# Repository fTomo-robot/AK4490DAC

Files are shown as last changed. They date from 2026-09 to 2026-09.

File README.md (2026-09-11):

# AK4490DAC

AKM(旭化成エレクトロニクス)の **AK4490**(32bit プレミアムDAC)と **AK4118**(SPDIFレシーバー)を使ったUSB DACのKiCadプロジェクト。

## 経緯

元の回路図(Eagle形式、`NEWDAC.sch`)はWindows PC上にのみ存在しており、このリポジトリ作成時点では発見できていません。
このプロジェクトは、JLCPCBに発注した際の製造データ(ガーバー・BOM・部品配置データ)から構成部品を復元し、KiCadで新規に組み直した上で、USB入力段・電源・出力段を改良したものです。

- `reference/NEWDAC_original_BOM.txt` : 元のEagle回路図から書き出された部品表(オリジナル、参考用)
- `reference/PnP_NEWDAC_*.txt` : 元の部品配置(Pick & Place)データ(参考用)

## 回路構成(改良版)

```
PC --USB--> SA9227(非同期USBオーディオ) --I2S--------------------+
                                                                  |
   (同軸/光)--SPDIF--> DA103C(絶縁トランス) --> AK4118(SPDIFレシーバ)
                                                    |  I2S        |
                                                    v              v
                                                74LS157(2:1 I2Sセレクタ)
                                                                  |
                                                                  v
                                                             AK4490(DAC)
                                                                  |  差動アナログ出力
                                                                  v
                                                    MUSES8920 x3(差動→SE変換 + LPF)
                                                                  |
                                                                  v
                                                              ライン出力
```

- **USB入力(U2 SA9227)**: Savitech製の非同期USBオーディオストリーミングコントローラ。32bit/384kHzまで対応し、旧PCM2704C(16bit/48kHz止まり)のボトルネックを解消。SPDIF送受信も内蔵
  - **要注意**: SA9227は動作に外部I2C EEPROM(`U8`, 24LC02)へのファームウェア書き込みが必須。書き込み用のファームウェアイメージは別途入手が必要
- **入力切り替え(U7, 74LS157)**: USB(SA9227のI2S出力)とSPDIF(AK4118のI2S出力)を1系統に統合してAK4490へ
- **絶縁(T1, DA103C)**: Murata製パルストランスでSPDIF入力経路をガルバニック絶縁
- **SPDIF受信(U5, AK4118)**: 同軸/光デジタル入力を受信・PLLでクロック再生成しI2Sに変換
- **D/A変換(U6, AK4490)**: 差動電流出力を生成。リファレンス電圧まわりは徹底したデカップリング
- **出力段(IC5-7, MUSES8920)**: 旧TL072から低ノイズ・低歪みのオーディオ用オペアンプに変更(ピン互換のドロップイン)
- **電源(IC1-4, ADP7142)**: 旧LM1117(ノイズ大きめの汎用LDO)から、Analog Devices製の低ノイズLDOに変更。3.3V×3・5.0V×1
- **リセット(U3/U4, TCM809)**: AK4118・AK4490それぞれのパワーオンリセットシーケンシング

## 注意事項

- `AK4118` / `AK4490` / `DA103C` / `SA9227` のシンボル・フットプリントは、旭化成系は過去の検証済みEagleライブラリから、SA9227は公式データシート(Savitech BRAVO-DSD SA9227 v1.3)のピン配置表から復元したもの
- 実際の配線(ネット接続)はまだ行っていない。KiCad上で全ICを配置しただけの状態
- SA9227のファームウェア(EEPROM書き込みイメージ)は別途入手・準備が必要
- ADP7142/MUSES8920/TCM809/BSS138/74LS157はKiCad標準ライブラリのシンボル・フットプリントをそのまま使用

## 次回作業予定(方針変更)

USB入力段について、SA9227のファームウェア/EEPROM書き込みが手間・コスト面で見合わないと判断し、**方針を変更**することにした(2026-09-12時点、回路図は未反映):

- **USB入力ICの自作(SA9227)はやめる**。市販の完成品コンバータを外付けで使う
  - 候補: Cubilux USB-C to SPDIF(TOSLINK)変換アダプタ(¥2,500前後、48kHz/24bit〜192kHz/24bit、ドライバ不要)
  - 元のBOMがUSB Type-Cコネクタ(`TYPE-C-31-M-12`)だったため、変換アダプタもそのまま挿せる
- 上記に伴い、次回は回路図から **U2(SA9227)・U8(24LC02 EEPROM)・U7(74LS157マルチプレクサ)を撤去**
- 代わりに **AK4118のSPDIF入力(RX0ピン)へTOSLINK光入力ジャックを追加**
- 検討したが採用しなかった他のUSB IC案(参考): PCM2704C(現状維持案)、TE7022L(EEPROM任意で24bit/96kHz)、CM6631A(LQFP-100・要ファーム)、CP2114(Silicon Labs製・EOL/48kHz止まりのため見送り)、Amanero Combo384モジュール(高性能だが¥15,400と割高)

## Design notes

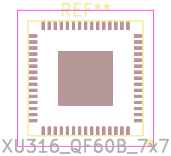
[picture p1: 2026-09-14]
.codex-work/fpcheck/XU316_QF60B_7x7.png

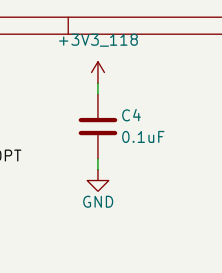
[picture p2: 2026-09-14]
.codex-work/power-layout/bypass.png

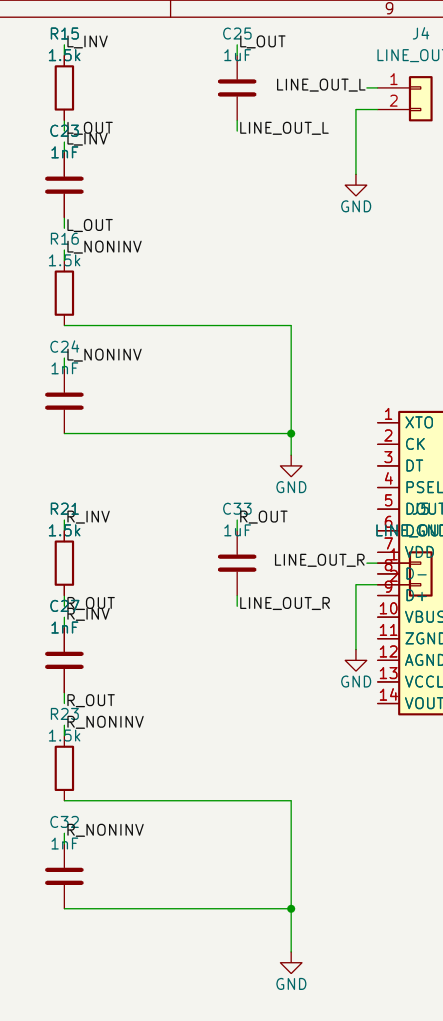
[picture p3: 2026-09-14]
.codex-work/power-layout/filters.png

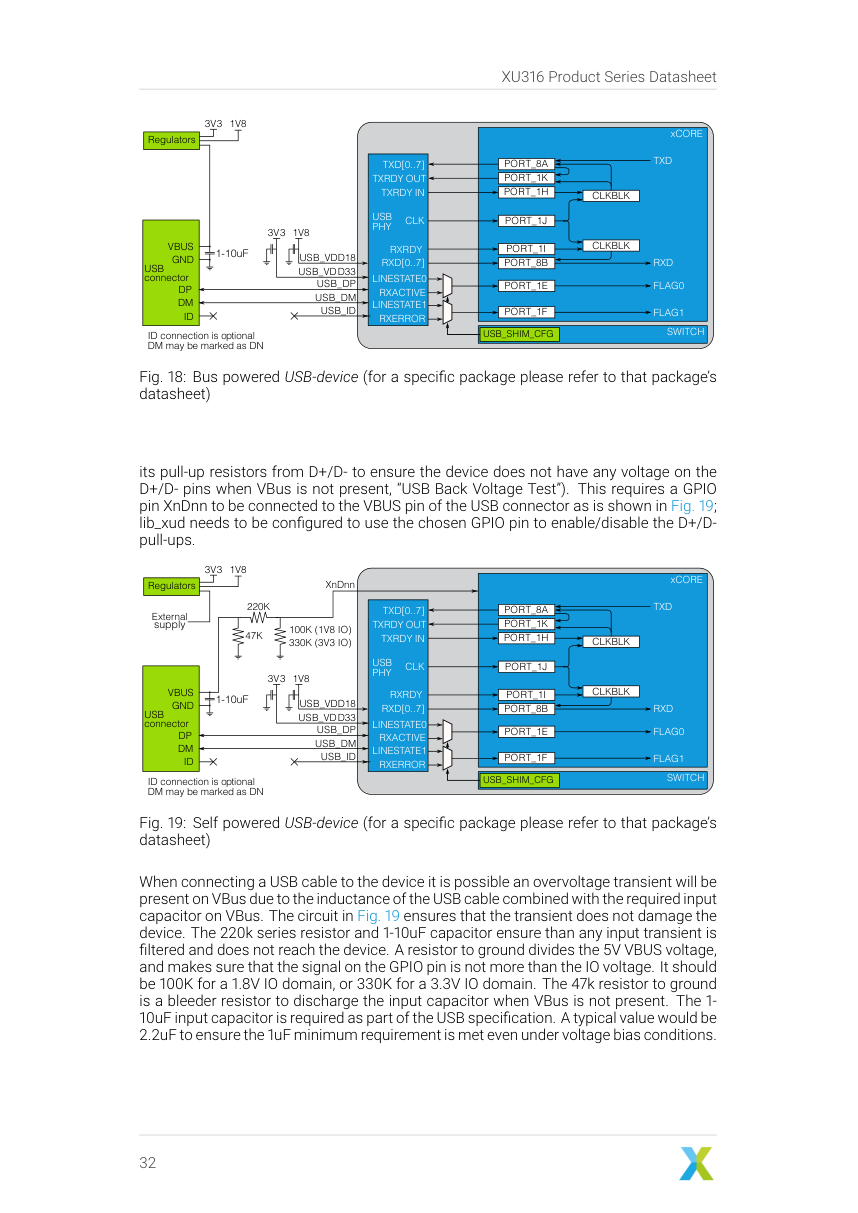
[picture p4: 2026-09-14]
.codex-work/xu316/sources/xmos-page32.png

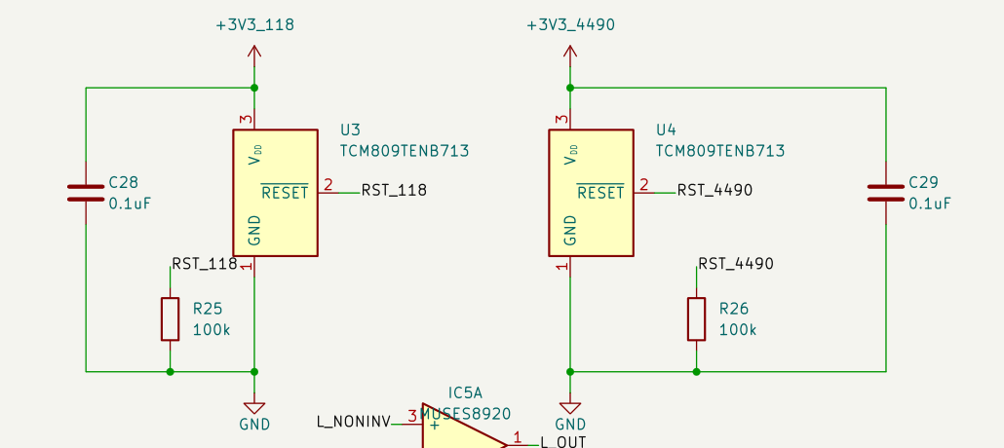
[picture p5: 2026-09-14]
.codex-work/power-layout/reset.png

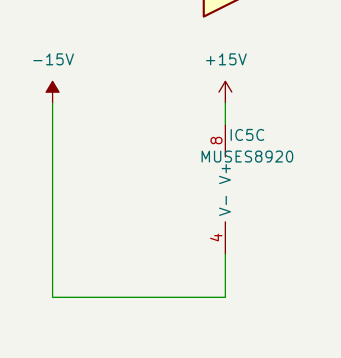
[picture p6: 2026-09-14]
.codex-work/power-layout/analog.png

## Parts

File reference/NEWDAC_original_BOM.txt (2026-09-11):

Partlist exported from C:/Users/zhigu/Desktop/NEWDAC.sch at 2023/01/06 15:23

Qty Value         Device          Package               Parts                                                                                                                                                                                                     Description                                                                                                 AVAILABILITY COPYRIGHT                                                DESCRIPTION                                                            MANUFACTURER_PART_NUMBER MF                   MFR_NAME          MP            MPN          OC_FARNELL OC_NEWARK PACKAGE                  POPULARITY PRICE PURCHASE-URL                                                   SPICEPREFIX TP_SIGNAL_NAME
21                C-EU050-024X044 C050-024X044          C2, C3, C5, C6, C7, C8, C10, C11, C13, C14, C15, C16, C17, C18, C19, C20, C21, C22, C23, C24, C25                                                                                                         CAPACITOR, European symbol                                                                                                                                                                                                                                                                                                                                                                        33                                                                              C                         
4                 CPOL-EUE5-10.5  E5-10,5               C1, C4, C9, C12                                                                                                                                                                                           POLARIZED CAPACITOR, European symbol                                                                                                                                                                                                                                                                                                                                                              23                                                                              C                         
20  1608          1608            CON                   U$7, U$17, U$18, U$21, U$22, U$23, U$24, U$25, U$26, U$28, U$29, U$36, U$37, U$43, U$44, U$45, U$46, U$51, U$61, U$62                                                                                                                                                                                                                                                                                                                                                                                                                                                                                                                                                                                                 
18  25V100        25V100          25V100                U$6, U$11, U$12, U$13, U$15, U$16, U$19, U$20, U$27, U$31, U$34, U$35, U$38, U$39, U$41, U$42, U$49, U$60                                                                                                                                                                                                                                                                                                                                                                                                                                                                                                                                                                                                             
1   946H          946H            946H                  U$8                                                                                                                                                                                                                                                                                                                                                                                                                                                                                                                                                                                                                                                                                                                   
1   AK4118        AK4118          QFP50P900X900X160-48N U$1                                                                                                                                                                                                                                                                                                                                                                                                                                                                                                                                                                                                                                                                                                                   
1   AK4490        AK4490          QFP50P900X900X160-48N U$2                                                                                                                                                                                                                                                                                                                                                                                                                                                                                                                                                                                                                                                                                                                   
2   B2B-PH-K-S    B2B-PH-K-S      B2B-PH-K-S            X2, X4                                                                                                                                                                                                    JST PH series header 2.00mm pitch disconnectable crimp style connectors, vertical (side entry type), 2 pins                                                                                                                                                                                                                                                                                                                                                                                                 
1   B3B-PH-K-S    B3B-PH-K-S      B3B-PH-K-S            X3                                                                                                                                                                                                        JST PH series header 2.00mm pitch disconnectable crimp style connectors, vertical (side entry type), 3 pins                                                                                                                                                                                                                                                                                                                                                                                                 
1   B4B-PH-K-S    B4B-PH-K-S      B4B-PH-K-S            X1                                                                                                                                                                                                        JST PH series header 2.00mm pitch disconnectable crimp style connectors, vertical (side entry type), 4 pins                                                                                                                                                                                                                                                                                                                                                                                                 
2   BNX016-01     BNX016-01       FIL_BNX016-01         FL1, FL2                                                                                                                                                                                                  Check availability                                                                                          In Stock                                                               LC EMI Filter 5th Order Low Pass 2 Channel - 15 A Block, 4 Lead                                Murata Electronics                     BNX016-01                                       Block-4 Murata                      None  https://pricing.snapeda.com/search/part/BNX016-01/?ref=eda                               
1   BSS138        BSS138          SOT23                 Q1                                                                                                                                                                                                        BSS138 N-Channel Logic Level Enhancement Mode Field Effect Transistor                                                                                                                                                                                                             Fairchild                                            BSS138       9845330    67R2009                                                                                                                                      
1   DA103C        DA103C          DA103C_MUR            T1                                                                                                                                                                                                                                                                                                                                 Copyright (C) 2022 Ultra Librarian. All rights reserved.                                                                        DA103C                                        Murata                                                                                                                                                                                               
3   FG            FG              FG                    U$33, U$40, U$47                                                                                                                                                                                                                                                                                                                                                                                                                                                                                                                                                                                                                                                                                                      
3   LM1117MP-3.3  LM1117MP-3.3    SOT223                IC3, IC5, IC6                                                                                                                                                                                             800mA Low-Dropout Linear Regulator                                                                                                                                                                                                                                                Texas Instruments                                    LM1117MP-3.3 9778195    28X3416                                                                                                                                      
1   LM1117MP-5.0  LM1117MP-5.0    SOT223                IC4                                                                                                                                                                                                       800mA Low-Dropout Linear Regulator                                                                                                                                                                                                                                                Texas Instruments                                    LM1117MP-5.0 9778209    28X3417                                                                                                                                      
1   MCWI03        MCWI03          MCWI03                U$57                                                                                                                                                                                                                                                                                                                                                                                                                                                                                                                                                                                                                                                                                                                  
1   PCM2704CDBR   PCM2704CDBR     DB28                  U1                                                                                                                                                                                                                                                                                                                                 Copyright (C) 2022 Ultra Librarian. All rights reserved.                                                                        PCM2704CDBR                                   Texas Instruments                                                                                                                                                                                    
1   Q             Q               Q                     U$3                                                                                                                                                                                                                                                                                                                                                                                                                                                                                                                                                                                                                                                                                                                   
45  R             R               1608                  1, 2, 11, 12, 13, 14, 15, 16, 17, 18, 19, 20, 21, 22, 23, 24, 25, 26, 27, 28, 29, 30, 31, 32, 33, 34, 35, 36, 37, 38, 39, 40, U$9, U$10, U$14, U$32, U$48, U$50, U$52, U$53, U$54, U$55, U$56, U$58, U$59                                                                                                                                                                                                                                                                                                                                                                                                                                                                                                             
1   SN74LS06NSR   SN74LS06NSR     SOIC127P780X200-14N   U2                                                                                                                                                                                                        HEX INVERTER BUFFERS Check availability                                                                     In Stock                                                               6-ch, 4.75-V to 5.25-V bipolar inverters with open-collector outputs                           Texas Instruments                      SN74LS06NSR                                     SOP-14 Texas Instruments            None  https://pricing.snapeda.com/search/part/SN74LS06NSR/?ref=eda                             
2   TCM809RENB713 TCM809RENB713   SOT95P237X112-3N      U$4, U$5                                                                                                                                                                                                  Check availability                                                                                          In Stock                                                               Processor Supervisor 2.63V 1 Active Low/Push-Pull 3-Pin SOT-23 T/R                             Microchip Technology                   TCM809RENB713                                   SOT-23 Microchip                    None  https://pricing.snapeda.com/search/part/TCM809RENB713/?ref=eda                           
3   TL072P        TL072P          DIL08                 IC1, IC2, IC7                                                                                                                                                                                             OP AMP                                                                                                                                                                                                                                                                                                                                                                                            13                                                                                                        
2   TPB1,27       TPB1,27         B1,27                 INT0, INT1                                                                                                                                                                                                Test pad                                                                                                                                                                                                                                                                                                                                                                                          19

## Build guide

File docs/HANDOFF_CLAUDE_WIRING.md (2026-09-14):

# Claude向け引継ぎ資料：AK4490DAC 回路図配線

作成日: 2026-09-14  
作成者: Codex

## 依頼内容

ユーザーからの依頼は「回路図で配線を進められそうな部分は進める。都度、部品位置は見やすいように変更してよい」。

不確かな仕様を推測で確定せず、公式データシートと既存の部品Descriptionから意図を判断できる部分まで配線した。

## 作業対象

現在の編集済みプロジェクト:

```text
C:\Users\ftomo\Documents\ChatGPT\AK4490DAC
```

主要ファイル:

```text
AK4490DAC.kicad_sch       編集済み回路図（作業継続対象）
AK4490DAC.kicad_sym       プロジェクト専用シンボル
AK4490DAC.kicad_pro       KiCadプロジェクト設定
AK4490DAC.kicad_pcb       基板。今回未編集
AK4490DAC_wired.pdf       編集後の確認用PDF
docs/WIRING_PROGRESS.md   今回の変更概要
```

コピー元は次の既存リポジトリ。ただし、コピー元にはユーザーまたは別セッションの未コミット変更があったため、今回の編集結果はまだ戻していない。

```text
C:\Users\ftomo\Documents\GitHub\AK4490DAC
```

コピー元の確認時点の状態:

```text
 M AK4490DAC.kicad_sch
 M AK4490DAC.kicad_sym
?? .codex-work/
?? .wiring-cleanup/
?? docs/
?? hardware/
```

コピー元を上書きする場合は、双方の差分を確認してからマージすること。単純コピーで上書きしないこと。

## 現在の回路構成

```text
USB-C J2
  -> ISOUSB211 U3
  -> XU316 U2
  -> I2S (BICK/LRCK/SDATA/MCLK)
  -> AK4490 U6
  -> MUSES8920 IC5
  -> LINE_OUT_L / LINE_OUT_R
```

電源はJ1の9〜12 V入力からIC9で約5.5 Vを作り、複数の低ノイズLDOへ分配する構成。

## 今回実施した変更

### 1. 電源配線

- J1 `+VIN_RAW` → IC9 AMS1117入力を接続。
- IC9のR3/R4分圧を配線し、出力を `+5V5_PRE` と命名。
- `+5V5_PRE` をIC1/IC2/IC3/IC4/IC8/IC10/IC11のINとENへ接続。
- 各LDOのGNDを接続。
- 各LDO出力を以下のレールへ接続。

| LDO | 出力ネット | 用途 |
|---|---|---|
| IC1 | `+3V3_XU` | XU316 I/O、ISOUSB211 Side 2、QSPI |
| IC10 | `+1V8_XU` | XU316 1.8 V系、ISOUSB211 Side 2 |
| IC11 | `+0V9_XU` | XU316コア |
| IC2 | `+3V3_4490` | AK4490 DVDD・制御系 |
| IC3 | `+3V3A_4490` | AK4490 AVDD |
| IC4 | `+5V_4490_L` | AK4490 VDDL/VDDL* |
| IC8 | `+5V_4490_R` | AK4490 VDDR/VDDR* |

### 2. AK4490周辺

- U6のDVDD/DVSS、AVDD/AVSSを接続。
- VDDL/VDDL*、VSSL/VSSL*を接続。
- VDDR/VDDR*、VSSR/VSSR*を接続。
- VCML/VCMRとC8/C9を接続。
- C10〜C13を各電源レールとGNDへ接続。
- C8〜C13をDAC/REFERENCEブロックへ移動し、基準電圧周辺をまとめた。

### 3. XU316周辺

- U2 XIN/XOUTをY1 24 MHz水晶およびC34/C35へ接続。
- 旧AK4118用だったリセット監視回路をXU316用に転用。
- リセットネットを `XU_RST_N` に変更し、U2 RST_Nへ接続。
- 未使用と判断できるGPIOにNo Connectを配置。

I2SのGPIO割り当ては既存の暫定値を維持した。ファームウェア仕様確定前に変更しないこと。

### 4. USB・ISOUSB211周辺

- USB-CのSBU1/SBU2をNo Connect指定。
- ISOUSB211の未使用ステータス出力V1OK/V2OKをNo Connect指定。
- Side 2の既存電源接続は維持。
- Side 1のV3P3V1、V1P8V1_A、V1P8V1_Bは必要なデカップリング部品が存在しないため未接続のまま残した。

### 5. 参照番号・部品修正

- 重複していたTCM809の参照番号を次のように変更。

```text
XU316用リセット: U3 -> U8
AK4490用リセット: U4 -> U9
```

- IC11は「TPS7A20-ADJ」とされていたが、TPS7A20は固定出力品のみ。公式の0.9 V固定SOT-23-5品 `TPS7A2009PDBVR` へ変更。
- IC11用として置かれていたR29/R30は `DNP` 表記に変更。現在も回路図上には残しているので、次の整理時に削除してよい。
- 過去のレイアウト作業で残っていた電気的に空の電源スタブを除去。

## ERC結果

KiCad 10.0.3で確認。

```text
変更前: 135件（error 128 / warning 7）
変更後:  17件（error 10 / warning 7）
```

最終内訳:

| ERC種類 | 件数 | 状態 |
|---|---:|---|
| lib_symbol_mismatch | 5 | 既存の標準ライブラリ差分 |
| pin_not_connected | 5 | U1の2ピン、ISOUSB211 Side 1の3ピン |
| power_pin_not_driven | 3 | `+VIN_RAW`、VBUS、USB_GNDにPWR_FLAGなし |
| pin_not_driven | 1 | U1入力 |
| missing_power_pin | 1 | U1電源ユニット未配置 |
| missing_input_pin | 1 | U1の未配置ゲート |
| missing_unit | 1 | U1の未配置ゲート |

最終ERC JSON:

```text
.codex-work/wiring/final-erc.json
```

実行コマンド:

```powershell
& 'C:\Program Files\KiCad\10.0\bin\kicad-cli.exe' sch erc `
  --format json --severity-all `
  -o '.codex-work\wiring\final-erc.json' `
  'AK4490DAC.kicad_sch'
```

`kicad-cli`実行時にHKCUレジストリへの書き込み拒否メッセージが多数出るが、ERC・ネットリスト・PDFの生成自体は成功している。

## 次に進められる作業

優先順:

1. ISOUSB211 Side 1のデカップリング回路を追加する。
   - V3P3V1からUSB_GND
   - V1P8V1_AからUSB_GND
   - V1P8V1_BからUSB_GND
   - TIデータシートでは各1.8 Vピンに個別のコンデンサ群を要求しているため、既存部品の流用ではなく部品追加が必要。
2. 全LDOの入力・出力コンデンサを追加する。
   - 特にTPS7A20は出力に最低1 µFが必要。
   - 現在のC10〜C13はAK4490近傍の0.1 µFデカップリングであり、LDO安定化コンデンサの代用にはしない。
3. U1（SN74LS06NSR）の用途を決める。
   - 現在はAユニットだけ配置され、全く接続されていない。
   - 旧回路の残骸ならシンボル全体を削除する。
   - 使用するなら全ユニットと電源ユニットを配置して接続する。
4. `+VIN_RAW`、VBUS、USB_GNDにPWR_FLAGを配置してERCの供給元判定を明示する。
5. R29/R30（DNP）と関連する `+0V9_XU_FB` ラベルを削除して表示を整理する。
6. XU316のI2S GPIOとQSPI信号割り当てをファームウェア側と照合する。
7. 回路図確定後にPCBへ反映する。現時点のPCBは今回の変更を反映していない。

## 注意すべき設計課題

- ISOUSB211 Side 1をデカップリングなしで完成扱いにしない。
- TPS7A2009の入力上限は6 V。必ずIC9後段の `+5V5_PRE` から給電し、`+VIN_RAW`へ直結しない。
- AK4490の品種表記が旧AK4490EQ相当のシンボルになっている。調達対象の型番と電源仕様を発注前に再確認する。
- C34/C35の18 pFは仮値。Y1の実部品と基板寄生容量から再計算する。
- XU316 QF60Bフットプリント寸法・Pin 1方向は推定情報を含むため、機械図面で再検証する。
- ERCが17件まで減っていても、電源容量、起動シーケンス、熱、USB SI、アナログ音質を保証するものではない。

## 作業補助ファイル

```text
.codex-work/wiring/before-wiring.kicad_sch  今回変更前の回路図
.codex-work/wiring/baseline-erc.json        変更前ERC
.codex-work/wiring/final-erc.json           変更後ERC
.codex-work/wiring/baseline.net             変更前ネットリスト
.codex-work/wiring/final.net                変更後ネットリスト
.codex-work/wiring/final.png                レンダリング確認画像
```

以下のスクリプトは変更過程の再現・調査用。ただし `wire_schematic.py` は追記型で非冪等なので、編集済み回路図に再実行しないこと。

```text
.codex-work/wiring/analyze.py
.codex-work/wiring/list_components.py
.codex-work/wiring/list_labels.py
.codex-work/wiring/netlist_analyze.py
.codex-work/wiring/wire_schematic.py
.codex-work/wiring/cleanup_stubs.py
```

## 参照した公式資料

- XMOS XU316-1024-QF60B Datasheet: https://www.xmos.com/file/xu316-1024-qf60b-datasheet?version=latest
- TI ISOUSB211 Datasheet: https://www.ti.com/lit/ds/symlink/isousb211.pdf
- TI TPS7A20 Datasheet: https://www.ti.com/lit/ds/symlink/tps7a20.pdf
- TPS7A2009PDBVR製品ページ: https://www.ti.com/product/TPS7A20/part-details/TPS7A2009PDBVR

## 完了条件の目安

- ISOUSB211と全LDOに必要なデカップリング部品が追加されている。
- U1を使用または削除する判断が完了している。
- 意図的なNC以外の `pin_not_connected` が0件。
- PWR_FLAG追加後、意図しない `power_pin_not_driven` が0件。
- ネットリストで電源ドメイン（USB_GNDとメインGND）が絶縁されたまま。
- PDFレンダリングでラベル重なりや用紙外部品がない。
- PCB更新前にユーザーへ、追加部品と型番変更の確認を求める。

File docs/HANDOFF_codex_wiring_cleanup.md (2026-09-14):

# 引継ぎ資料: 回路図ワイヤー整理 (Codex向け)

作成日: 2026-09-14 / 作成者: Claude (Sonnet 5)

## 依頼内容(スコープ)

対象は **`AK4490DAC.kicad_sch`(回路図)のワイヤーの見た目の整理のみ**。

- 電気的なネット接続(どのピンとどのピンが繋がっているか)は**変更しない**
- ワイヤーの経路・ジャンクション位置・ラベルの配置など、**見た目(交差・重なり・遠回り)をきれいにする**のが目的
- 部品の定数値・フットプリント・ピン配置の修正は対象外
- `AK4490DAC.kicad_pcb`(基板)は対象外 ※後述の通りまだトレース配線が0本の状態で、今回は触らない

## プロジェクト概要

AKM AK4490(32bit DACチップ)を使ったUSB DACのKiCadプロジェクト。

**注意: `README.md` の内容は古いまま**(PCM2704C + AK4118 + SPDIF光入力 + SA9227構想の説明)。
直近の一連のコミットで USB入力段を XMOS XU316 ベースに全面移行しているため、実態と乖離している。README は今回のタスクでは信用しないこと。

### 現在の回路構成(2026-09-13時点、最新コミット)

```
PC --USB-C(J2)--> ISOUSB211DPR(U3, USBアイソレータ) --USB2.0--> XU316(U2, XMOS xcore.ai)
                                                                        | I2S (BICK/LRCK/SDATA/MCLK)
                                                                        v
                                                                   AK4490(U6, DAC)
                                                                        | 差動アナログ出力
                                                                        v
                                                              MUSES8920/TL072 出力段(IC5, IC8-9)
                                                                        |
                                                                        v
                                                                    ライン出力
```

- **U2 = XU316-1024-QF60B-C24**: 自作60ピンシンボル + 自作パラメトリックQFN-60(0.4mmピッチ)フットプリント。**フットプリント寸法は推定値**(QF60Bというパッケージ呼称からの逆算)。実物の機械図面が手に入り次第、ピン1コーナーの向き含めて検証が必要(基板発注前必須)
- **U3 = ISOUSB211DPR**: USBアイソレータ。J2(USB_GNDドメイン)とXU316(メインGND)を絶縁。Side1はJ2のVBUSからバスパワー(内部LDOでV3P3V1/V1P8V1生成)、Side2は外部供給の+3V3_XU/+1V8_XUレール
- **U4 = W25Q32JVSSIQ**: QSPIブートフラッシュ。ファームウェア(未着手・スコープ外)用
- **Y1**: 24MHz水晶(XU316用)。負荷容量値は暫定(18pF、他クリスタルに合わせただけ)
- **IC10 (LP5907 1.8V) / IC11 (TPS7A20 ADJ品 + R29/R30で0.9V)**: XU316の電源用に新設。IC1はAK4118撤去に伴い+3V3_XUに転用
- **I2Sの信号名(_BICK/_LRCK/_SDATA/_MCLK)はXU316のGPIO割り当てのプレースホルダ**。実際のピン機能はファームウェアで決まるため、この命名はあくまで仮
- JP2: 5ピンJTAGデバッグヘッダ

### 撤去済み(過去にあったが現在は存在しない部品)

PCM2704C、AK4118、SPDIF光入力(TORX147FT)、DA103C絶縁トランス、SA9227、74LS157マルチプレクサ、24LC02 EEPROM ― これらは全て撤去済み。回路図中に見当たらなくても正常。

## ファイル構成の注意点

- `AK4490DAC.kicad_sch` — 触ってよい対象(今回のメイン)
- `AK4490DAC.kicad_sym` — このプロジェクト専用ライブラリ(XU316, ISOUSB211等のカスタムシンボル定義)。ワイヤー整理では触らない想定
- `AK4490DAC.kicad_pcb` — **触らない**。フットプリント14個が配置されているだけで、配線トレース・ビア・ベタ(zone)は0。今回のスコープ外
- `hardware/generate_schematic.py` と `.codex-work/` ディレクトリ — **これは別セッションで走らせた、ゼロから回路図を自動生成する未完成の試作コード**。現行の `AK4490DAC.kicad_sch` とは無関係で、書き込み先も別パス(`hardware/*.kicad_sch`)。混同しないこと。触る必要なし
- `AK4490DAC-backups/` — 過去のZIPバックアップ。参照不要
- `reference/` — 旧Eagle設計の部品表・実装データ(参考用、現行設計とは対応が薄い)

## 既知の状態・現在のERC結果

`kicad-cli sch erc` を実行すると **135件の違反**が出るが、これは**全て既知・想定内**のもの:

| type | 件数 | 内容・原因 |
|---|---:|---|
| pin_not_connected | 89 | 主に電源系IN/EN配線がまだ「ユーザーの本配線パス待ち」の状態(意図的に未接続のまま残されている) |
| power_pin_not_driven | 30 | 同上、電源ネットの供給元配線待ち |
| pin_not_driven | 8 | 主にU1(74LS06N)まわり、未使用ゲート等 |
| lib_symbol_mismatch | 5 | 標準ライブラリ(TL072, 74LS06N, USB_C_Receptacle等)のキャッシュと現在のライブラリ版の差分。実害なし、警告のみ |
| missing_unit | 1 | U1(74LS06N)の一部ユニット未配置 |
| missing_power_pin | 1 | 既知の1件 |
| missing_input_pin | 1 | U1(74LS06N)関連 |

**作業完了の目安**: ワイヤー整理後にもう一度 `sch erc` を実行し、この件数・カテゴリの内訳が(ネット接続を変えていなければ)同じままであることを確認する。件数が増えていたら、意図せずネットを切ってしまった可能性が高い。

コマンド例:
```
"C:\Program Files\KiCad\10.0\bin\kicad-cli.exe" sch erc --format json --output erc_after.json AK4490DAC.kicad_sch
```

## 過去にハマった落とし穴(要注意)

1. **一括での大量ワイヤー挿入でkicad-cliがsegfaultした事例あり**(2026-09-13、XU316追加時)。原因は特定できず(個別に分割して再現させると問題なし)。大きな変更は一度に流し込まず、**小分けにして都度 `sch erc` で読み込み確認**しながら進めるのが安全
2. **座標の偶然の一致(coordinate collision)によるバグ**が過去に発生している。ワイヤーやジャンクションの座標を機械的にずらす/移動する際は、既存の他要素と座標が衝突しないよう注意
3. 部品削除時、ダングリングになった配線・ラベルはUUID一致で特定して削除する手法が過去使われている(座標ベースでの削除は事故のもと)

## 推奨の進め方

1. 現状の `sch erc` 結果(件数・カテゴリ)をまず記録しておく(このドキュメントの表と照合)
2. ワイヤー整理は**電気的に等価な経路の付け替え**(交差の解消、直角配線への整列、ラベル位置調整など)にとどめる
3. まとまった単位(シート単位・回路ブロック単位など)で区切り、都度 `git commit` して差分を追えるようにする
4. 各区切りごとに `sch erc` を実行し、違反の件数・カテゴリが変化していないことを確認する
5. 完了後、最終的な `sch erc` 結果をコミットメッセージに残す(このプロジェクトの既存コミットの慣習に合わせる)

## 参考: 直近のコミット履歴

```
8e62d29 Add XU316, ISOUSB211, QSPI flash: USB/SPDIF -> XMOS migration
ce33006 Remove PCM2704C, AK4118 and SPDIF path ahead of XU316 migration
9f22a35 Convert power/ground net labels to real KiCad power symbols
2c88caa Decide SPDIF input as optical-only, switch USB to Type-C
5c2dc8f Consolidate output op-amps: move R channel onto IC5, remove IC6
```

KiCadバージョン: 10.0(`C:\Program Files\KiCad\10.0`)

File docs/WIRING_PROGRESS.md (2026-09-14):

# 回路図配線進捗（2026-09-14）

## 今回接続した範囲

- `+VIN_RAW` → IC9（AMS1117）→ `+5V5_PRE` のプリレギュレータと分圧抵抗 R3/R4
- `+5V5_PRE` から IC1/IC2/IC3/IC4/IC8/IC10/IC11 の入力・EN・GND
- 各LDO出力から `+3V3_XU`、`+1V8_XU`、`+0V9_XU`、`+3V3_4490`、`+3V3A_4490`、`+5V_4490_L`、`+5V_4490_R`
- AK4490 の DVDD/DVSS、AVDD/AVSS、VDDL/VSSL、VDDR/VSSR、VCML/VCMR と C8〜C13
- XU316 の XIN/XOUT と 24 MHz 水晶、XU316リセット
- USB-C SBU、ISOUSB211 V1OK/V2OK、未使用XU316 GPIOへ明示的なNC指定

## 整理・修正

- C8〜C13をAK4490基準電圧ブロックへ集約。
- R3/R4をIC9の近くへ移動し、分圧関係が読める配置に変更。
- 重複していたリセットICの参照番号を U8/U9 に変更。
- 旧AK4118用リセットを `XU_RST_N` としてXU316へ転用。
- IC11は可変型ではなく固定0.9 V品 `TPS7A2009PDBVR` に修正。R29/R30はDNP表記。
- 過去のレイアウト整理で残っていた電気的に空の電源スタブを除去。

## ERC結果

変更前は135件、変更後は17件。

| 種類 | 件数 | 残件の意味 |
|---|---:|---|
| lib_symbol_mismatch | 5 | 標準ライブラリと回路図キャッシュの差分 |
| pin_not_connected | 5 | U1の2ピン、ISOUSB211 Side 1の内部LDO端子3ピン |
| power_pin_not_driven | 3 | `+VIN_RAW`、VBUS、USB_GNDにPWR_FLAGが未配置 |
| pin_not_driven | 1 | 未使用のU1入力 |
| missing_power_pin | 1 | U1の電源ユニット未配置 |
| missing_input_pin | 1 | U1の未配置ゲート |
| missing_unit | 1 | U1の未配置ゲート |

## 次に必要な設計判断

1. ISOUSB211 Side 1の V3P3V1 と2本の V1P8V1 に、データシート指定の個別デカップリングを追加する。
2. 各LDOの安定性確保用に、入力・出力コンデンサを追加して容量と定格を確定する。
3. 用途不明で全ゲート未使用の U1（74LS06）を削除するか、使用回路を決める。
4. `+VIN_RAW`、VBUS、USB_GNDへERC用PWR_FLAGを追加する。
5. XU316のI2S GPIO割り当てはファームウェア仕様確定後に再確認する。

ERCは接続規則の機械検査であり、電源容量、起動シーケンス、音質、部品定格の妥当性までは保証しない。

## 追記（2026-09-14、Claude担当分）

Codexの引継ぎ（`docs/HANDOFF_CLAUDE_WIRING.md`）を受けて、「次に必要な設計判断」1〜4を実施。

### 1. U1（SN74LS06N）を削除

- 全ピン未接続・全ユニット未配置のまま放置されていた残骸コンポーネント。使用箇所なしと判断し、シンボルインスタンスと`lib_symbols`キャッシュを削除。
- これだけでERC違反が17件→10件に減少（missing_unit/missing_input_pin/missing_power_pin/pin_not_driven/pin_not_connectedのU1関連7件が解消）。

### 2. PWR_FLAGを3箇所に追加

`power:PWR_FLAG`シンボルを新規に`lib_symbols`へ登録し、以下3ネットへ配置：

- `+VIN_RAW`（IC9 VIピン付近）
- `VBUS`（U3 VBUS1ピン付近）
- `USB_GND`（U3 GND1ピン付近）

→ `power_pin_not_driven`の3件が解消（10件→7件）。

### 3. ISOUSB211（U3）Side 1のデコップリングを追加

TIデータシート指定通り、Side 1の3ピンに個別コンデンサを追加（新規 C36〜C38、フットプリントは他のC0603系に合わせて`Capacitor_SMD:C_0603_1608Metric`、GND側はローカルラベル`USB_GND`で接続）：

- C36: V3P3V1 - USB_GND、1uF
- C37: V1P8V1_A - USB_GND、0.1uF
- C38: V1P8V1_B - USB_GND、0.1uF

→ `pin_not_connected`の3件が解消（7件→4件、残りは全て既存のlib_symbol_mismatch警告のみ）。

### 4. 全LDO（IC1/IC2/IC3/IC4/IC8/IC9/IC10/IC11）へ入出力コンデンサを追加

これまで8個のLDO/プリレギュレータには入出力コンデンサが1個も無かった（ERCでは検出されない電気的な欠落）。新規 C39〜C54（16個）を追加：

| LDO | IN側 | OUT側 |
|---|---|---|
| IC1 (+3V3_XU) | C39 1uF | C40 1uF |
| IC2 (+3V3_4490) | C41 1uF | C42 1uF |
| IC3 (+3V3A_4490) | C43 1uF | C44 1uF |
| IC4 (+5V_4490_L, TPS7A2050) | C45 1uF | C46 1uF |
| IC8 (+5V_4490_R, TPS7A2050) | C47 1uF | C48 1uF |
| IC9 (+5V5_PRE, AMS1117プリレグ) | C53 10uF | C54 10uF |
| IC10 (+1V8_XU) | C49 1uF | C50 1uF |
| IC11 (+0V9_XU, TPS7A2009) | C51 1uF | C52 1uF |

全てIN/OUTピンから直接ワイヤーで分岐し、GND側はローカルラベル`GND`で接続（既存C10〜C13と同じ流儀）。値は各データシートの最小推奨値（LP5907系・TPS7A20系は1uF、AMS1117は10uF）。**実際の負荷電流・過渡応答・基板寄生を踏まえた最終値の確定は未実施**（次回課題）。

### 5. R29/R30（DNP）と`+0V9_XU_FB`ラベルを削除

IC11が固定0.9V品に変更済みでDNP指定されていた旧フィードバック分圧回路（R29・R30・関連ワイヤー4本・`+0V9_XU_FB`ラベル2箇所）を完全撤去。

### 最終ERC結果

```text
変更前（Codex引継ぎ時点）: 17件（error 10 / warning 7）
Claude作業後:              4件（error 0 / warning 4、全てlib_symbol_mismatch警告のみ）
```

`kicad-cli sch erc --format json --severity-all` / `sch export netlist` / `sch export pdf` を実行しエラーなしを確認済み。JSON各段階のログは `.codex-work/wiring/after-*-erc.json` に保存。

### まだ手つかずの項目（次回への引継ぎ）

- **LDO入出力コンデンサの最終値確定**: 今回追加したのはデータシート最小推奨値。実負荷・トランジェント・レイアウト寄生を踏まえた再検討が必要。
- **XU316のI2S GPIO / QSPI信号割り当て**: ファームウェア仕様確定後に照合すること（未着手、ハードウェアだけでは決められない）。
- **PCBへの反映**: `AK4490DAC.kicad_pcb`は今回未編集。回路図がある程度固まった段階でネットリストを反映すること。
- **AK4490の型番確認**: シンボルが旧AK4490EQ相当のまま。発注前に実際の調達型番と電源仕様を再確認。
- **C34/C35（XU316水晶負荷容量）**: 18pFは仮値、実部品のCLと基板寄生から再計算が必要。
- **XU316 QF60Bフットプリント**: 寸法・Pin1方向とも推定。機械図面で要検証。
- **このコピー（`C:\Users\ftomo\Documents\ChatGPT\AK4490DAC`）はコピー元の `C:\Users\ftomo\Documents\GitHub\AK4490DAC` にまだマージされていない**。マージ前に両者の差分を確認すること（コピー元にも別セッションの未コミット変更が残っている可能性がある）。

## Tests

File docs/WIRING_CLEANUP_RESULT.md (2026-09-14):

# 回路図レイアウト整理（2026-09-14）

## 変更内容

- 1枚の回路図上で、左から USB-C → ISOUSB211 → XMOS XU316 → AK4490 → 左右アナログ出力の順に配置。
- 7つの機能ブロックを枠線・見出しで区分。電源回路は下段に集約。
- 用紙外にあったXMOS、USBアイソレータ、QSPI、クロック、JTAGを用紙内に配置。
- XU316とISOUSB211のピン列を縦方向に2倍に広げ、余分なシンボル本体の空白を縮小。回路図キャッシュと専用シンボルライブラリの両方を更新。
- 抵抗・コンデンサの参照番号と定数を本体の右側に配置。
- ブロックをまたぐ信号は既存のネットラベルで接続。全体を一覧できるよう、階層シートは追加していない。

## 検証

- KiCad 10.0.3で回路図を再読込し、PDFを出力・目視確認。
- ネットリスト154ネットの接続端子集合（部品番号・ピン番号）は変更前後ですべて一致。
- 全95シンボルインスタンスのUUID、ユニット、ピン識別情報、定数、フットプリントなどのプロパティ値は変更なし。
- ERCの種類、件数、対象UUIDは変更前後で一致。
- 基板ファイルは変更していない。

| ERC種類 | 変更前 | 変更後 |
|---|---:|---:|
| lib_symbol_mismatch | 5 | 5 |
| missing_input_pin | 1 | 1 |
| missing_power_pin | 1 | 1 |
| missing_unit | 1 | 1 |
| pin_not_connected | 89 | 89 |
| pin_not_driven | 8 | 8 |
| power_pin_not_driven | 30 | 30 |

重大度別: error: 128, warning: 7。合計135件。

## 既存の未解決事項

U3（リセットIC / USBアイソレータ）とU4（リセットIC / QSPI）に参照番号の重複があり、ネットリスト出力時にアノテーション警告が出る。番号変更は今回行っていないため、上記ネットリスト比較はこの既存状態での比較である。電源未接続などの既存ERC違反も維持しており、電気設計の完成を意味しない。

確認用PDF: `AK4490DAC_layout.pdf`

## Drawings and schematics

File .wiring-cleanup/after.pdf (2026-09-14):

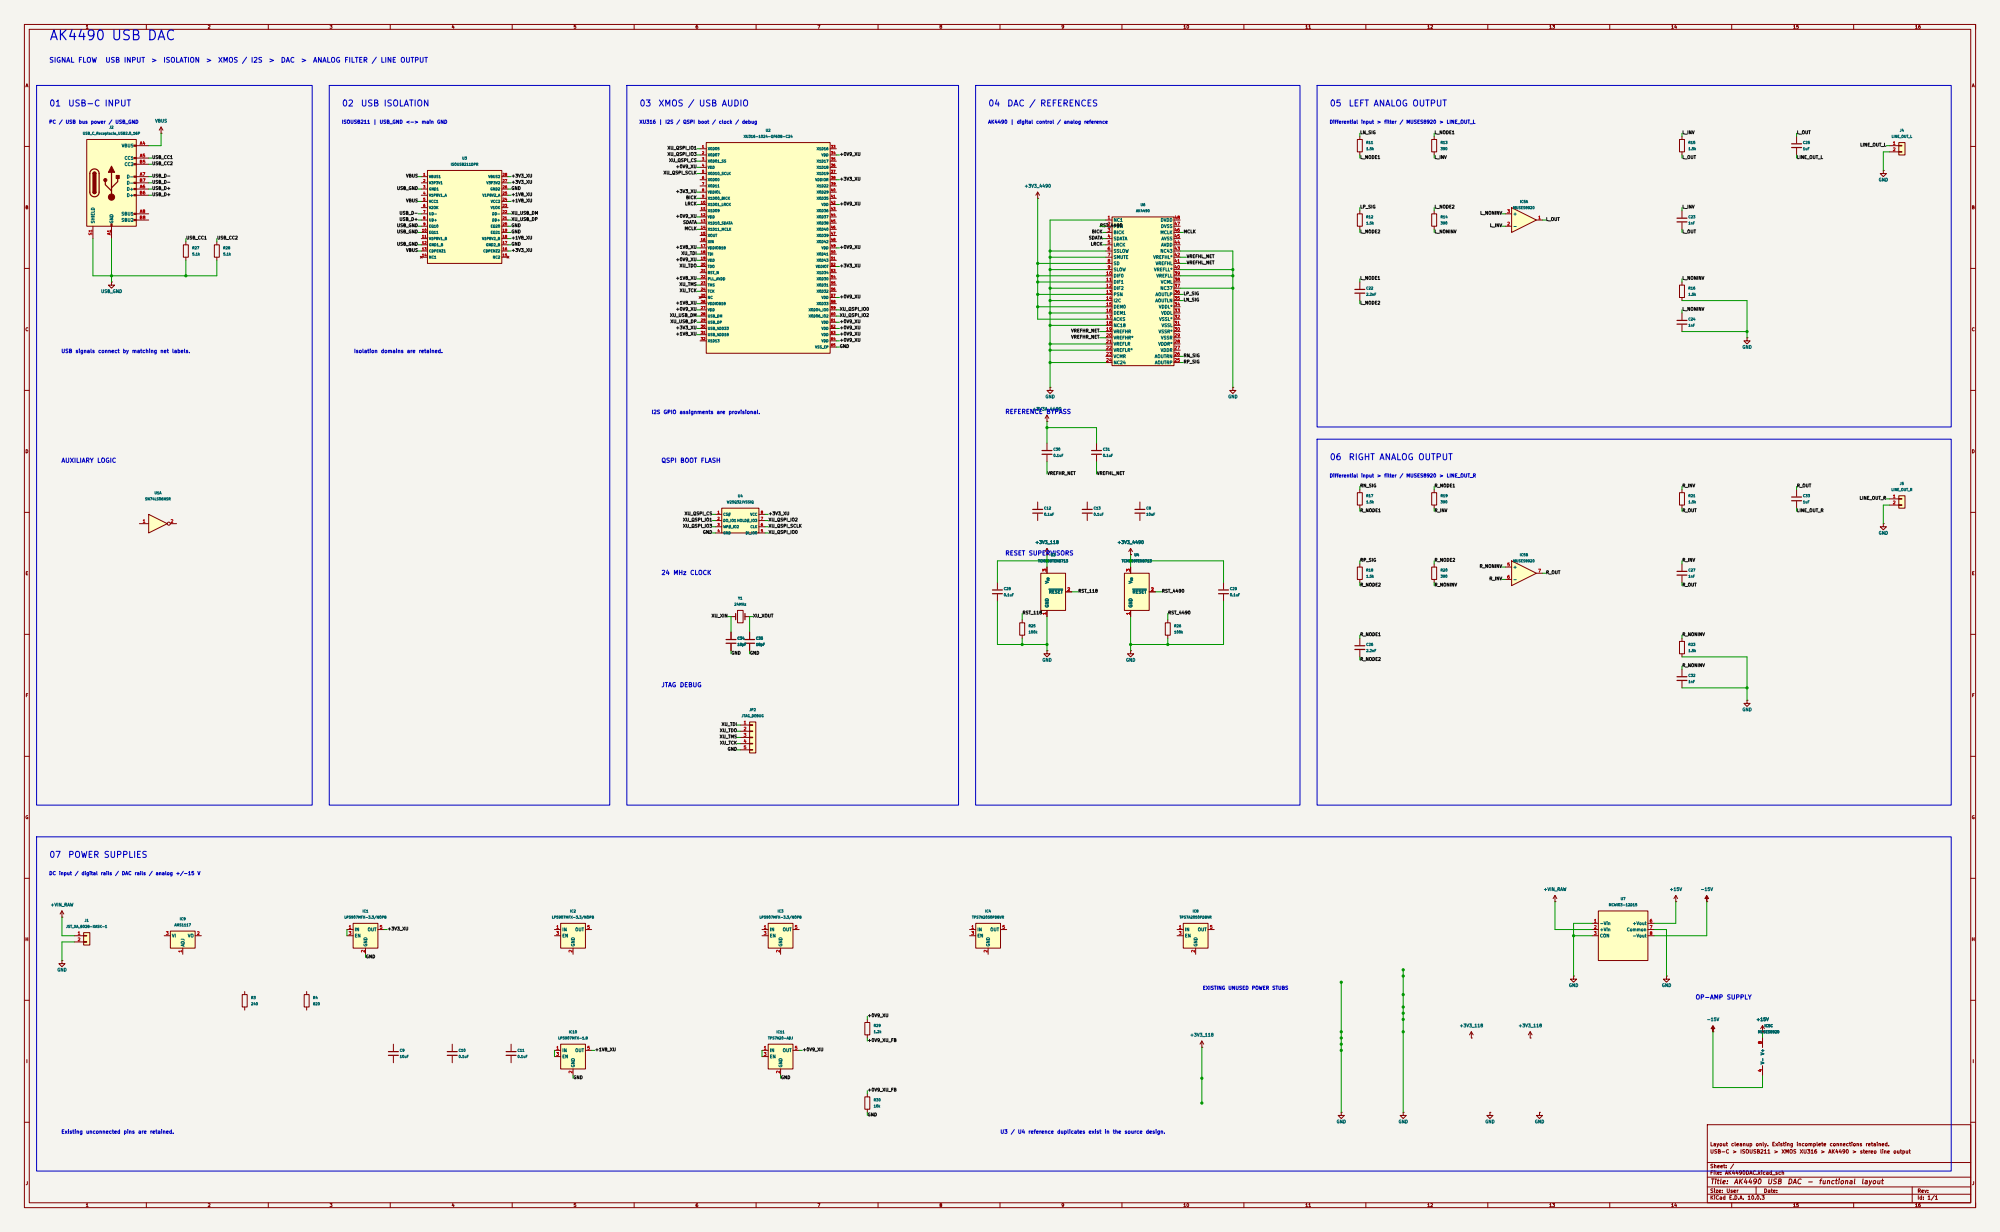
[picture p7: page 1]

SIGNAL FLOW USB INPUT > ISOLATION > XMOS / I2S > DAC > ANALOG FILTER / LINE OUTPUT

AK4490 | digital control / analog reference 01 USB-C INPUT

04 DAC / REFERENCES
Differential input > filter / MUSES8920 > LINE_OUT_L Differential input > filter / MUSES8920 > LINE_OUT_R

PC / USB bus power / USB_GND

USB signals connect by matching net labels.

Isolation domains are retained.

I2S GPIO assignments are provisional.

DC input / digital rails / DAC rails / analog +/-15 V

EXISTING UNUSED POWER STUBS

Existing unconnected pins are retained.

U3 / U4 reference duplicates exist in the source design.

Layout cleanup only. Existing incomplete connections retained. USB-C > ISOUSB211 > XMOS XU316 > AK4490 > stereo line output

Sheet: /

File: AK4490DAC.kicad_sch
Title: AK4490 USB DAC - functional layout

Size: User | Rev:
KiCad E.D.A. 10.0.3 | Id: 1/1

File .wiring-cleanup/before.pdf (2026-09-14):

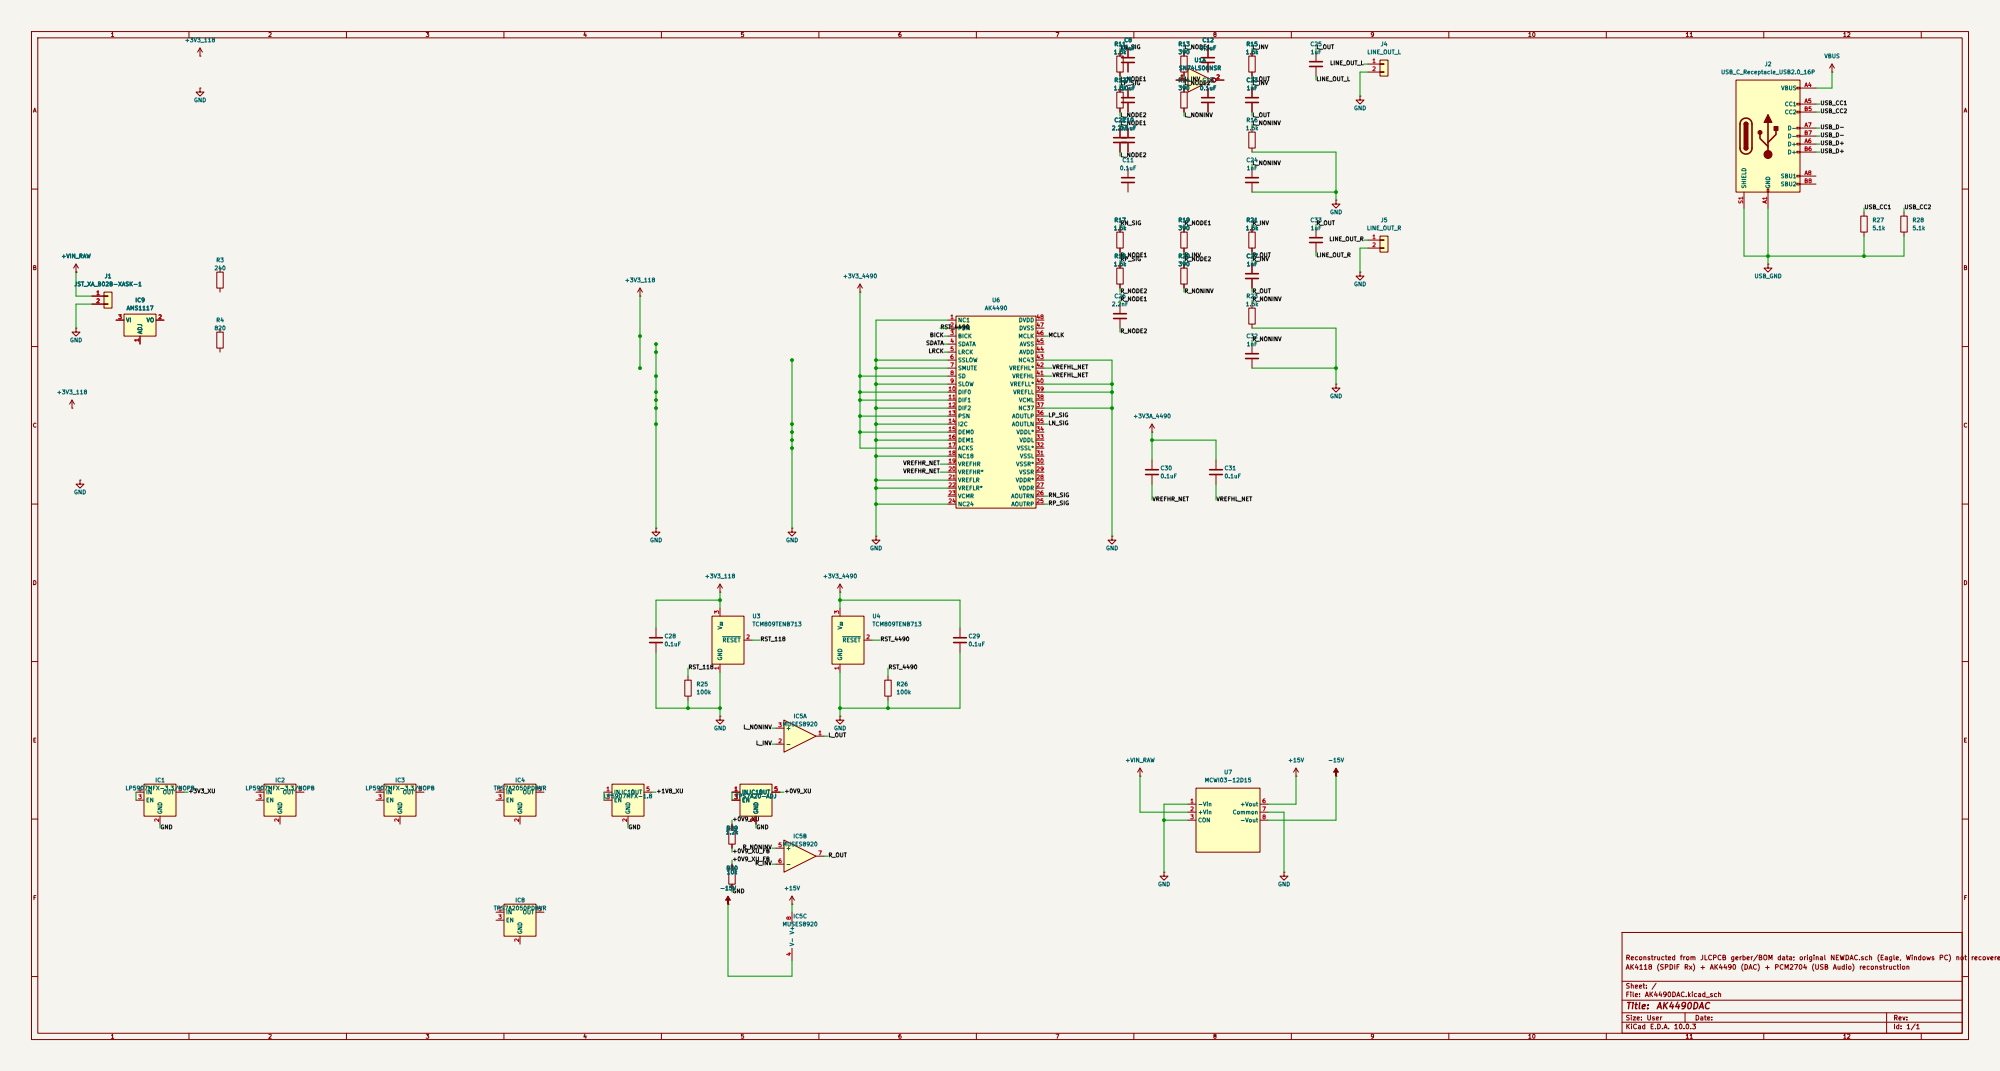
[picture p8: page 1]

Reconstructed from JLCPCB gerber/BOM data; original NEWDAC.sch (Eagle, Windows PC) not recovered
AK4118 (SPDIF Rx) + AK4490 (DAC) + PCM2704 (USB Audio) reconstruction

Size: User | Rev:
KiCad E.D.A. 10.0.3 | Id: 1/1

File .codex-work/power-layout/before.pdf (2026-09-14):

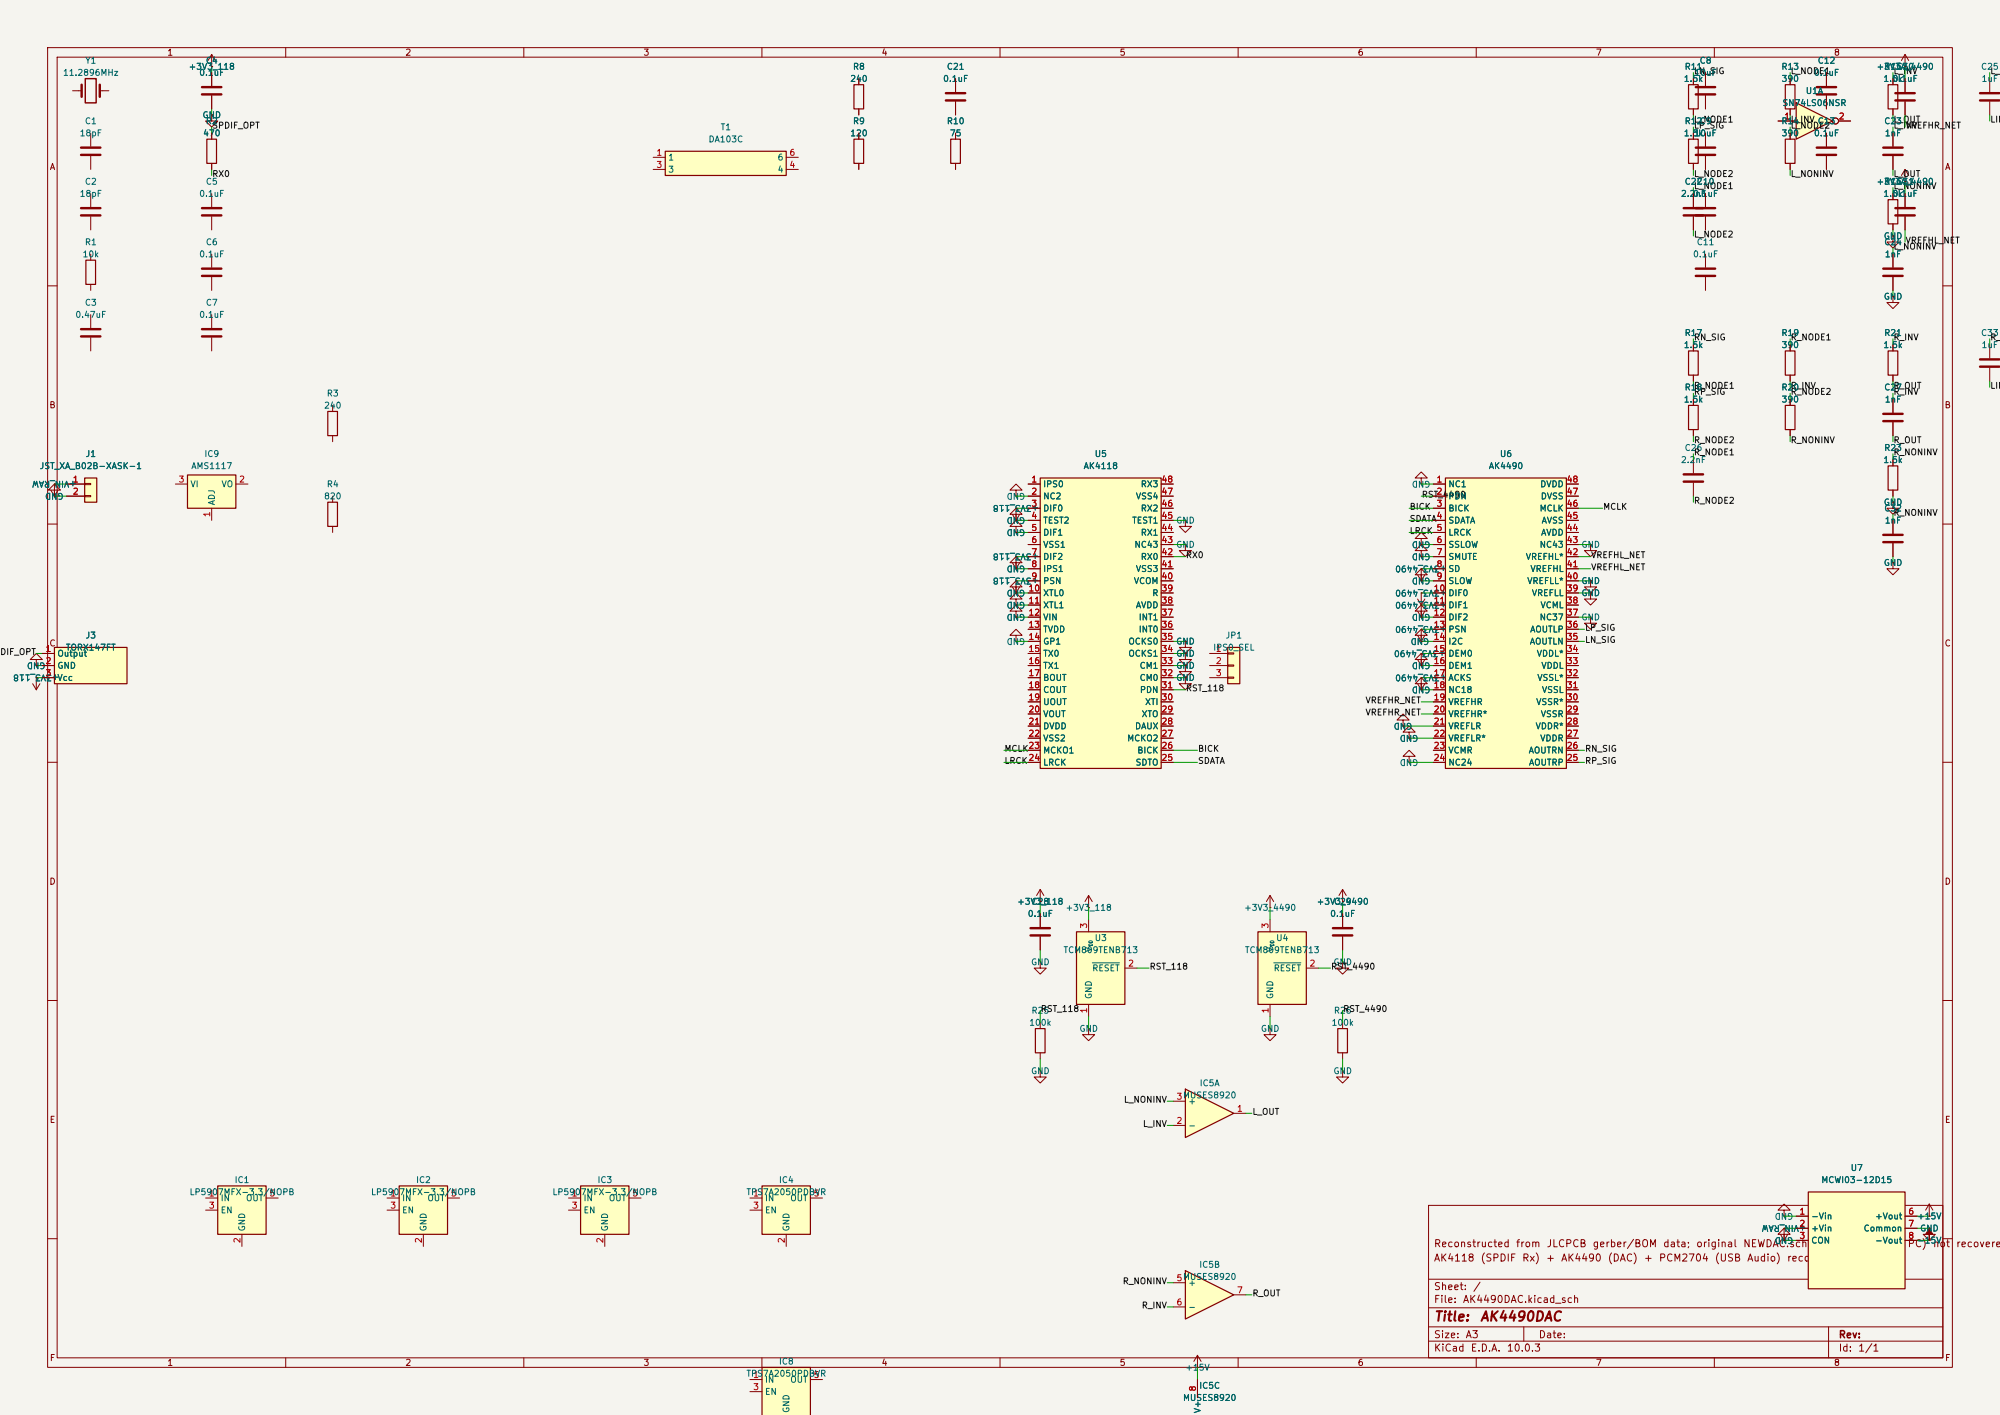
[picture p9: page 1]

AK4118 (SPDIF Rx) + AK4490 (DAC) + PCM2704 (USB Audio) reconstruction

Size: A3 | Rev:
KiCad E.D.A. 10.0.3 | Id: 1/1 | F Date:

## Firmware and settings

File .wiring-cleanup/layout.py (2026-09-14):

import re,json,collections
from pathlib import Path
TOKEN=re.compile(r'"(?:\\.|[^"\\])*"|[^\s()]+|[()]')
def parse(s):
 stack=[]; root=None
 for t in TOKEN.findall(s):
  if t=='(':
   a=[]
   if stack: stack[-1].append(a)
   stack.append(a)
  elif t==')':
   root=stack.pop()
  else: stack[-1].append(t)
 return root
def children(n,k): return [x for x in n if isinstance(x,list) and x and x[0]==k]
def child(n,k): return next(iter(children(n,k)),None)
def val(n,k):
 c=child(n,k); return c[1] if c else None
def unq(x): return json.loads(x) if x and x.startswith('"') else x
p=Path('.wiring-cleanup/before.kicad_sch'); root=parse(p.read_text(encoding='utf-8'))
if __name__=='__main__':
 print(collections.Counter(x[0] for x in root if isinstance(x,list)))
 for s in children(root,'symbol'):
  props={unq(x[1]):unq(x[2]) for x in children(s,'property')}
  print(props.get('Reference'),props.get('Value'),child(s,'at'),val(s,'unit'))
 for t in children(root,'text'): print('TEXT',t[:3])

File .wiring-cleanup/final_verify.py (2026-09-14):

exec(open('.wiring-cleanup/layout.py',encoding='utf-8-sig').read().split('if __name__')[0])
from collections import Counter
before=parse(Path('.wiring-cleanup/before.kicad_sch').read_text(encoding='utf-8'));after=parse(Path('AK4490DAC.kicad_sch').read_text(encoding='utf-8'))
def components(r):
 return {val(s,'uuid'):(val(s,'lib_id'),val(s,'unit'),tuple((p[1],p[2]) for p in children(s,'property')),tuple(tuple(p) for p in children(s,'pin'))) for s in children(r,'symbol')}
assert components(before)==components(after)
def erc(name):
 d=json.loads(Path('.wiring-cleanup/'+name+'-erc.json').read_text(encoding='utf-8'))
 vs=[v for s in d['sheets'] for v in s['violations']]
 return Counter(v['type'] for v in vs),Counter(v['severity'] for v in vs),Counter((v['type'],tuple(sorted(i.get('uuid','') for i in v['items']))) for v in vs)
b,a=erc('before'),erc('after');assert b==a
print('ERC counts and affected UUIDs identical:',a[:2]);print('All 95 symbol instance UUIDs, pins, values and footprints unchanged.')
report='''# 回路図レイアウト整理（2026-09-14）

## 変更内容

- 1枚の回路図上で、左から USB-C → ISOUSB211 → XMOS XU316 → AK4490 → 左右アナログ出力の順に配置。
- 7つの機能ブロックを枠線・見出しで区分。電源回路は下段に集約。
- 用紙外にあったXMOS、USBアイソレータ、QSPI、クロック、JTAGを用紙内に配置。
- XU316とISOUSB211のピン列を縦方向に2倍に広げ、余分なシンボル本体の空白を縮小。回路図キャッシュと専用シンボルライブラリの両方を更新。
- 抵抗・コンデンサの参照番号と定数を本体の右側に配置。
- ブロックをまたぐ信号は既存のネットラベルで接続。全体を一覧できるよう、階層シートは追加していない。

## 検証

- KiCad 10.0.3で回路図を再読込し、PDFを出力・目視確認。
- ネットリスト154ネットの接続端子集合（部品番号・ピン番号）は変更前後ですべて一致。
- 全95シンボルインスタンスのUUID、ユニット、ピン識別情報、定数、フットプリントなどのプロパティ値は変更なし。
- ERCの種類、件数、対象UUIDは変更前後で一致。
- 基板ファイルは変更していない。

| ERC種類 | 変更前 | 変更後 |
|---|---:|---:|
'''
for k,v in sorted(a[0].items()):report+=f'| {k} | {v} | {v} |\n'
report+='\n重大度別: '+', '.join(f'{k}: {v}' for k,v in a[1].items())+'。合計135件。\n'
report+='''
## 既存の未解決事項

U3（リセットIC / USBアイソレータ）とU4（リセットIC / QSPI）に参照番号の重複があり、ネットリスト出力時にアノテーション警告が出る。番号変更は今回行っていないため、上記ネットリスト比較はこの既存状態での比較である。電源未接続などの既存ERC違反も維持しており、電気設計の完成を意味しない。

確認用PDF: `AK4490DAC_layout.pdf`
'''
Path('docs/WIRING_CLEANUP_RESULT.md').write_text(report,encoding='utf-8')
import fitz
d=fitz.open('docs/AK4490DAC_layout.pdf');d[0].get_pixmap(matrix=fitz.Matrix(.8,.8)).save('.wiring-cleanup/final.png')

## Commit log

2026-09-11 Initial commit: AK4490DAC reconstruction from JLCPCB manufacturing data
    - KiCad project scaffold with all 15 major ICs placed (unwired)
    - AK4118/AK4490/DA103C symbols and DA103C footprint recovered from
    verified user Eagle library pinout data
    - PCM2704CDBR pinout is a best-effort placeholder, not verified
    - Original BOM/pick-and-place reference data included under reference/
    Claude-Session: https://claude.ai/code/session_01QHWVKPQryRUD2718hB4T9B
    [AK4490DAC.kicad_pcb, AK4490DAC.kicad_sch]
2026-09-11 Upgrade design: SA9227 USB async audio, ADP7142 LDOs, MUSES8920 op-amps
    - Replace PCM2704C (16bit/48kHz bottleneck) with SA9227 (32bit/384kHz
    async USB audio streaming controller, pinout verified against
    Savitech datasheet). Needs external I2C EEPROM (added, U8/24LC02)
    for firmware.
    - Add 74LS157 quad 2:1 mux (U7) to select between SA9227's I2S output
    and AK4118's recovered I2S before feeding AK4490.
    - Replace LM1117 LDOs (IC1-3 3.3V, IC4 5.0V) with Analog Devices
    ADP7142 low-noise LDOs for cleaner analog/digital rails.
    - Replace TL072 op-amps (IC5-7) with MUSES8920 (pin-compatible
    drop-in audio op-amp).
    - Reposition all symbols to eliminate layout overlaps.
    - Fix a corrupted AK4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
    [AK4490DAC.kicad_sch]
2026-09-11 Note planned direction change: drop SA9227, use external USB-SPDIF dongle
    Schematic unchanged. Decided (not yet implemented) to remove SA9227,
    its EEPROM, and the 74LS157 mux, and instead add a TOSLINK optical
    input jack to AK4118, using an off-the-shelf USB-C to SPDIF adapter
    (e.g. Cubilux, ~2500 yen) externally instead of an onboard USB IC.
    Also logs the other USB IC candidates considered and why they were
    passed over.
    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
2026-09-12 Fix AK4118/AK4490 symbol pins, wire I2S link, replace regulators, add power input
    Symbol fixes (AK4490DAC.kicad_sym), verified against AKM datasheets:
    - AK4118: pins 27/28/29/44/46/48 were mislabeled NC; corrected to
    MCKO2/DAUX/XTO/RX1/RX2/RX3
    - AK4490: pin 1 and 48 were swapped (DVDD/NC), and pins 14/16/18 had
    invalid names (INV/LDOE/TESTE); corrected to NC1/I2C/DEM1/NC18, and
    pin 48 is now DVDD
    Schematic changes (AK4490DAC.kicad_sch):
    - Added AK4118 support parts: 11.2896MHz crystal (Y1) + load caps,
    R pin resistor, VCOM cap, RX0 AC-coupling cap + 75R termination
    (per datasheet Fig.11/21) -- the original 2023 Eagle design lacked
    a crystal entirely and had no RX0 input network,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
    [AK4490DAC.kicad_sch]
2026-09-12 Fix PCM2704CDBR symbol: rebuild pin mapping from real TI datasheet
    The previous PCM2704CDBR symbol (both in the project symbol library and
    in the schematic's lib_symbols cache) had entirely fabricated pin names
    (MODE0/MODE1/IIS_BCK_SCLK/ISET/PLLFLT/DIFFOUT_HPCOM etc.) that did not
    match the actual chip. Rebuilt all 28 pins from TI datasheet SBFS036A
    Table 1 (DB/SSOP-28 package): XTO, CK, DT, PSEL, DOUT, DGND, VDD, D-,
    D+, VBUS, ZGND, AGNDL, VCCL, VOUTL, VOUTR, VCCR, AGNDR, VCOM, PGND,
    VCCP, HOST, HID0_MS, HID1_MC, HID2_MD, TEST1, TEST0, SSPND, XTI.
    Also fixes a schematic-file corruption bug from an earlier session: the
    lib_symbols cache block for PCM2704CDBR is NOT immediately followed by
    D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
    [AK4490DAC.kicad_sch]
2026-09-12 Add PCM2704C USB input circuit with transformer isolation from AK4118
    Places (unwired, matching this project's existing convention for
    support components -- see the wiring table below) all parts needed for
    the "SPDIF primary, USB via jumper" architecture:
    PCM2704C USB Audio DAC (bus-powered, isolated USB-side domain):
    - U2: PCM2704CDBR
    - Y2 + C14/C15: 12MHz crystal w/ 22pF load caps (TI SBFS036A Fig.34)
    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
    [AK4490DAC.kicad_sch]
2026-09-12 Add AK4490 differential I/V + diff-amp output stage components
    Places (unwired, per this project's convention) the analog output
    stage feeding off the already-placed IC5/IC6/IC7 (MUSES8920 dual
    op-amps) and Q1 (BSS138), using the AK4490's real differential current
    output pins (AOUTLP/AOUTLN/VCML and AOUTRP/AOUTRN/VCMR, per the
    pin-verified symbol) instead of a single-ended assumption.
    Topology: 3 op-amp units per channel (I/V converter x2 + differential
    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
    [AK4490DAC.kicad_sch]
2026-09-12 Fix reset supervisor (TCM809) threshold mismatch, add support parts
    The TCM809RENB713 placed for U3 (AK4118 reset) and U4 (AK4490 reset)
    back in the initial "upgrade" commit was never actually vetted against
    Microchip's datasheet (DS21661E). This is a real orderable part (R =
    2.55-2.70V threshold, ENB = SOT-23B marking code, both valid per the
    datasheet's marking/ordering tables) -- but the R threshold grade is
    specified by Microchip for 3.0V-nominal systems ("VDD = 3.3V for T/S,
    3.0V for R" per the electrical characteristics table). Our AK4118/
    AK4490 DVDD rails are 3.3V (from LP5907MFX-3.3), so R's ~2.63V typical
    threshold would only assert reset once the 3.3V rail sagged over 20%,
    well pa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
    [AK4490DAC.kicad_sch]
2026-09-12 Verify TCM809T reset supervisor selection and wire it into the circuit
    Verification against Microchip datasheet DS21661E and the AK4118/
    AK4490 datasheets (both require PDN = "L" held during power-up, then
    released to "H" once supply is stable -- Mouser AK4118A datasheet;
    AKM AK4490 datasheet MS1648-E-03):
    - Necessity: confirmed genuinely required, not just convention -- both
    DACs need an active power-on reset pulse on PDN, not a static tie.
    - Threshold: TCM809T (3.00-3.15V) matches the monitored 3.3V DVDD
    rails per Microchip's own "VDD=3.3V for T/S" pairing (fixed last
    commit).
    - Timing margin: TCM809's 140ms minimum RESET-active period vastly
    exceeds AK4490's 150ns minimum PDN pul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
    [AK4490DAC.kicad_sch]
2026-09-12 Remove Q1 (BSS138): orphaned leftover from the abandoned SA9227 design
    Audited Q1 the same way as the TCM809 reset ICs. Findings:
    - Added in ed632a9 ("Upgrade design: SA9227 USB async audio, ADP7142
    LDOs, MUSES8920 op-amps") alongside SA9227/24LC02/74LS157, but never
    mentioned in that commit's message, and its Description property was
    left blank.
    - Never wired to anything at any point in this repo's history (checked
    every commit touching AK4490DAC.kicad_sch) -- zero net connections,
    ever.
    - SA9227/24LC02/74LS157 were explicitly removed together in 4d609bf
    once the direction changed to external USB-SPDIF, but Q1 was missed
    from that removal list.
    BSS138 is a classic bidirection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
    [AK4490DAC.kicad_sch]
2026-09-12 Fix AK4118 pins 14-20/10-12: 2nd wave of un-verified pin errors
    Re-verified the full AK4118 pinout against the real AKM datasheet
    (Mouser/Qobuz-hosted AK4118A/AK4118 MS1042-E-01, Pin/Function table
    pages 4-5) while researching the reset-IC follow-up. Found the earlier
    "fix" pass (commit 4d609bf) was incomplete:
    - Pins 14-20 were left as fabricated no_connect placeholders (NC14-
    NC20). They are real pins: 14=GP1 (input, no function in our
    Parallel-mode config -- datasheet Note 1 says unused inputs must not
    float), 15=TX0, 16=TX1, 17=BOUT, 18=COUT, 19=UOUT, 20=VOUT (all
    outputs, safe to leave unconnected since they're not inputs).
    - Pins 10/11 (XTL0/XTL1, crystal frequency select) and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
    [AK4490DAC.kicad_sch]
2026-09-12 Wire AK4118's static mode-select pins per verified datasheet tables
    Wires 17 previously-placed-but-unconnected AK4118 pins using the same
    local-label style already used for the I2S links and reset ICs, based
    on the datasheet tables read in the previous commit:
    DIF2=H, DIF1=L, DIF0=H -> Table 15 Mode 5 (24bit I2S, matches the
    existing BICK/LRCK/SDATA/MCLK wiring)
    IPS1=L -> fixed; RX0/RX1 select stays on IPS0 (JP1)
    PSN=H -> Parallel Control Mode (this hardware-
    pin-strap design, not I2C/SPI control)
    XTL0=L, XTL1=L -> Table 4, matches the installed 11.2896MHz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
    [AK4490DAC.kicad_sch]
2026-09-13 Wire AK4490's static mode-select pins + VREF bias network
    Verified AK4490 against the real AKM datasheet (MS1648-E-03). Good
    news first: unlike AK4118, the AK4490 symbol's pin NUMBERING/NAMES
    from the earlier fix (4d609bf) were already fully correct against the
    real Pin Layout/Pin Functions tables (pages 5-7) -- no renaming needed
    here, just wiring the mode pins to their correct levels:
    SSLOW=L, SMUTE=L -> normal operation, mute released
    SD=H, SLOW=L -> Table 8: Short delay Sharp roll-off
    filter (the datasheet's own default)
    DIF2=L, DIF1=H, DIF0=H -> Table 20 Mode 3: 24bit I2S compatible,
    matching A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
    [AK4490DAC.kicad_sch]
2026-09-13 Add isolated +-15V supply (MCWI03-12D15) for output op-amp stage; fix missing op-amp units
    Per discussion: the output stage needs a true bipolar +-15V supply to
    match AKM's own reference circuits (Fig.40/41), and the user asked to
    reuse the same isolated DC-DC approach as the original NEWDAC Eagle
    design rather than build a virtual-ground single-supply version.
    Confirmed by reading NEWDAC.sch (Eagle XML): the original design used
    a MinMax MCWI03 series module (net "15V", same net feeding both this
    module and the LM1117 3.3V/5V regulators). Datasheet confirms the
    12V-input-family variant (MCWI03-12D15, accepts 4.5-18V in, +-15V out)
    matches: our main DC input works directly as input, no pre-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
    [AK4490DAC.kicad_sch]
2026-09-13 Place Fig.40 differential-to-single-ended output filter components
    Switched from the Fig.41 topology discussed earlier to Fig.40 (single
    op-amp per channel): the exact per-component node connections in
    Fig.41 could not be read with full confidence from the datasheet scan,
    and getting a differential audio output stage wrong is exactly the
    class of mistake this session has already made once (the earlier
    current-output/I-V assumption). Fig.40's values are all clearly
    legible and its frequency response is independently documented
    (Table 30), so it's the safer choice to implement correctly.
    Places (unwired) the classic 4-resistor difference-amplifier + 2-pole
    filter per channel, using AKM's exac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
    [AK4490DAC.kicad_sch]
2026-09-13 Wire the Fig.40 output filter network to AK4490 and the op-amps
    Connects the components placed in the previous commit into the actual
    difference-amplifier + 2-pole LPF per channel, using the project's
    established stub-wire + label style:
    AOUTxN/AOUTxP -> Ra1/Ra2 (1.5k) -> {NODE1,NODE2} -> Cdiff (2.2nF
    cross-coupled) -> Rb1/Rb2 (390R) -> op-amp -/+ inputs
    op-amp output <-> Rf/Cf (1.5k || 1nF) feedback to inverting input
    non-inverting input <-> Rg/Cg (1.5k || 1nF) to GND (mirrors the
    feedback impedance for balanced CMRR, per the difference-amp
    topology)
    op-amp output -> Cout (1uF) -> line-out connector
    L channel uses IC5 unit 1, R channel uses IC6 unit 1 (matches the
    Fig.40-top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
    [AK4490DAC.kicad_sch]
2026-09-13 Add MCWI03-12D15 footprint, remove spare IC7, terminate unused op-amp halves
    - Created AK4490DAC.pretty/MCWI03-12D15.kicad_mod: custom SIP-8 THT
    footprint (single row, 2.54mm pitch, pin 4 physically absent, 21.8x9.3mm
    body per MCWI03 series datasheet mechanical outline). Pad size/drill are
    estimated (1.8mm/1.0mm) and noted as needing verification against the
    datasheet drawing before fab. Wired the Footprint property to
    "AK4490DAC:MCWI03-12D15" in the .kicad_sym master, the schematic's
    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
    [AK4490DAC.kicad_sch]
2026-09-13 Consolidate output op-amps: move R channel onto IC5, remove IC6
    Per user request ("IC5,6は統合できないの？"): since each channel's
    Fig.40 filter op-amp only used one half of its dual MUSES8920 package
    (the other half was just terminated as a safety measure last commit),
    consolidated both channels onto a single physical IC instead of two -
    this is the standard approach for a stereo dual-op-amp stage and saves
    one IC from the BOM.
    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
    [AK4490DAC.kicad_sch]
2026-09-13 Decide SPDIF input as optical-only, switch USB to Type-C
    Per user decisions ("光のみでいいかな" / "USBはCに変更"):
    SPDIF input (J3): optical-only
    - Replaced the generic 2-pin placeholder with an actual optical receiver:
    Toshiba TORX147(F,T), a 3-pin TOSLINK module (Output/GND/Vcc) chosen
    specifically because its Vcc range (2.7-3.6V, typ 3.0V) runs directly
    off the existing +3V3_118 rail - no new 5V rail needed, unlike the more
    common TORX173/5V family. New custom symbol + footprint (SIP-8 3-pin
    THT, body dims from the datasheet drawing; screw-mount hole not
    modeled, noted for follow-up).
    - Rebuilt the RX0 front-end per AK4118 datasheet Fig.22 ("Consumer Input
    Circu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
    [AK4490DAC.kicad_sch]
2026-09-13 Convert power/ground net labels to real KiCad power symbols
    Per user request ("電源系はできるだけラベルではなくシンボルで対応したい"):
    replaced all 75 power/ground net-label instances (GND, +3V3_118,
    +3V3_4490, +3V3A_4490, +15V, -15V, +VIN_RAW, USB_GND, VBUS) with proper
    KiCad power symbols, leaving genuine signal/logic net labels (RST_118,
    RX0, USB_D+/-, the Fig.40 filter node names, etc.) untouched as plain
    labels - only true power/ground rails were converted.
    - GND / +15V / -15V / VBUS: use KiCad's real global power:GND,
    power:+15V, power:-15V, power:VBUS symbols verbatim.
    - +3V3_118 / +3V3_4490 / +3V3A_4490 / +VIN_RAW / USB_GND: no exact-name
    global symbol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
    [AK4490DAC.kicad_sch]
2026-09-13 Remove PCM2704C, AK4118 and SPDIF path ahead of XU316 migration
    Per user decision to replace both PCM2704C (USB audio) and AK4118
    (SPDIF receiver) with a single XU316-1024-QF60B-C24 (XMOS xCORE.ai),
    and to drop the optical SPDIF input entirely (USB-only device now):
    Removed entirely (component + all exclusive support parts + wiring):
    - U2 (PCM2704CDBR), Y2 (12MHz X'tal), R5/R6/R7 (USB D+/D- pullup/
    termination - not needed, XU316's USB PHY needs no external R per
    its datasheet's simplified reference diagram), C14-C20 (X'tal load
    caps + supply decoupling)
    - U5 (AK4118), Y1 (11.2896MHz X'tal), R1 (pin39 pulldown), R10 (RX1
    termination), C1/C2 (X'tal load caps), C3 (VCOM cap), C5/C6/C7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
    [AK4490DAC.kicad_sch]
2026-09-13 Add XU316, ISOUSB211, QSPI flash: USB/SPDIF -> XMOS migration
    Implements the XU316-1024-QF60B-C24 (XMOS xcore.ai) replacement for
    PCM2704C+AK4118, decided and refined over several rounds of discussion
    (power architecture, USB isolation approach and cost, GND domain
    strategy). Firmware is explicitly out of scope - hardware only.
    New parts:
    - U2 = XU316-1024-QF60B-C24, custom 60-pin symbol (all pins present,
    named/typed per XMOS datasheet SLLSFC5D... er, XU316 datasheet
    section 3/4 pin tables) + custom parametric QFN-60 0.4mm-pitch
    footprint (dimensions estimated from the QF60B package designator -
    verify against the real mechanical drawing, including pin-1 corner
    orientation, befor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
    [AK4490DAC.kicad_sch]
2026-09-14 Complete power/decoupling wiring; supersede concurrent layout cleanup
    Two independent sessions worked from commit 8e62d29 in parallel, in
    separate working copies:
    1. A Codex session in this repo (uncommitted) did a pure visual layout
    cleanup of AK4490DAC.kicad_sch/.kicad_sym - regrouped functional
    blocks, fit everything on one page, widened XU316/ISOUSB211 pin
    spacing. Verified electrically identical to 8e62d29 (same 154-net
    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
    [AK4490DAC.kicad_sch]
2026-09-14 Simplify PWR_FLAG lib_symbols cache to match project's KiCad 9.x schema
    The power:PWR_FLAG cache block added in 8d2d180 was copied verbatim
    from the installed KiCad 10.0 symbol library, which includes several
    newer property fields (do_not_autoplace, in_pos_files,
    duplicate_pin_numbers_are_jumpers) not present anywhere else in this
    file - this project's schematic is on the KiCad 9.x schema (version
    20250114, generator_version "9.0"). Simplified the block to match the
    plain style already used by the file's other power symbols (GND, VBUS,
    +15V, -15V).
    Unrelated finding while investigating a "failed to load" report:
    confirmed via kicad-cli that this project (both before and after
    today's change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
    [AK4490DAC.kicad_sch]
2026-09-14 Fix XU316 QF60B footprint: correct pin-1 orientation and EP size
    The custom footprint was built from an estimated 7x7mm/0.4mm-pitch
    guess (per its own description, "dimensions estimated from package
    designator QF60B... VERIFY before fab"). The real mechanical drawing
    (Fig.28) was already sitting in this repo at
    .codex-work/xu316/sources/xmos-page49.png from earlier datasheet
    research, unused until now. Comparing against it:
    - Body size (7.00mm BSC) and pin pitch (0.40mm BSC) were already
    correct.
    - Exposed pad (pin 65/VSS) was 5.15x5.15mm, ~43% oversized versus the
    datasheet's D2/E2/D3/E3 nominal of 3.60mm. Corrected to 3.6x3.6mm.
    Note: the datasheet dimensions this pad from two separ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
2026-09-14 回路図整えた
    [AK4490DAC.kicad_sch, before.kicad_sch]
2026-09-14 Refine DAC schematic power and analog sections
    [AK4490DAC.kicad_sch]
